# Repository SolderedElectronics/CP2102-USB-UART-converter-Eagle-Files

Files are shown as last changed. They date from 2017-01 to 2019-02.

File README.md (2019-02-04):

# CP2102 USB-UART adapter Eagle Files
## Image
CP2102 USB to UART adapter image
[CP2102 USB to UART adapter(100033)](https://e-radionica.com/en/usb-uart-adapter-with-cp2102-made-by-e-radionica.html)

## Description and details
This little adapter converts USB communication to UART using Silabs CP2102. Everything is packed on a small board. In addition to standard UART pins arranged in standard order: DTR, RXD, TXD, VCC, CTS, GND, other pins from the chip are available on the board: RST, Suspend, Suspend ', RI, DCD, DSR, RTS, CTS.

In addition, the board is a voltage regulator and a switch, it is possible to determine the output voltage of 3.3V or 5V, depending on the device you are using. Logic UART signal is always 3.3V, but do not worry, 5V devices will work without problems. There are also three LEDs, one for power indicator and one for each direction of UART communication.
 
- Dimensions: 25 x 35 mm
- USB - UART bridge: CP2102
- Input voltage: 5V (USB)
- Output voltage: 3.3V ili 5V
- Logic of UART signal: 3.3V

## Repository content
This repo contains Cadsoft Eagle .sch and .brd files for CO2102 breakout. It also contains schematic in .pdf created from .sch Eagle file. 
Files have been arranged into folders for navigating between different versions of board. 
Tip: layer 200 shows top silkscreen and layer 208 should be bottom silkscreen. tParts and bParts layers are not used in actual PCB. 

## Docs
- [CP2102 adapter product page](https://e-radionica.com/en/usb-uart-adapter-with-cp2102-made-by-e-radionica.html)

## Board versions
- v1.0 REV A - inital published version 

## License info
This product is open-source. Yay!
For any tech questions, contact us at techsupport@e-radionica.com
If you find an Issue, please open one at GitHub. If you can improve our product, fork us.

e-radionica.com Team.

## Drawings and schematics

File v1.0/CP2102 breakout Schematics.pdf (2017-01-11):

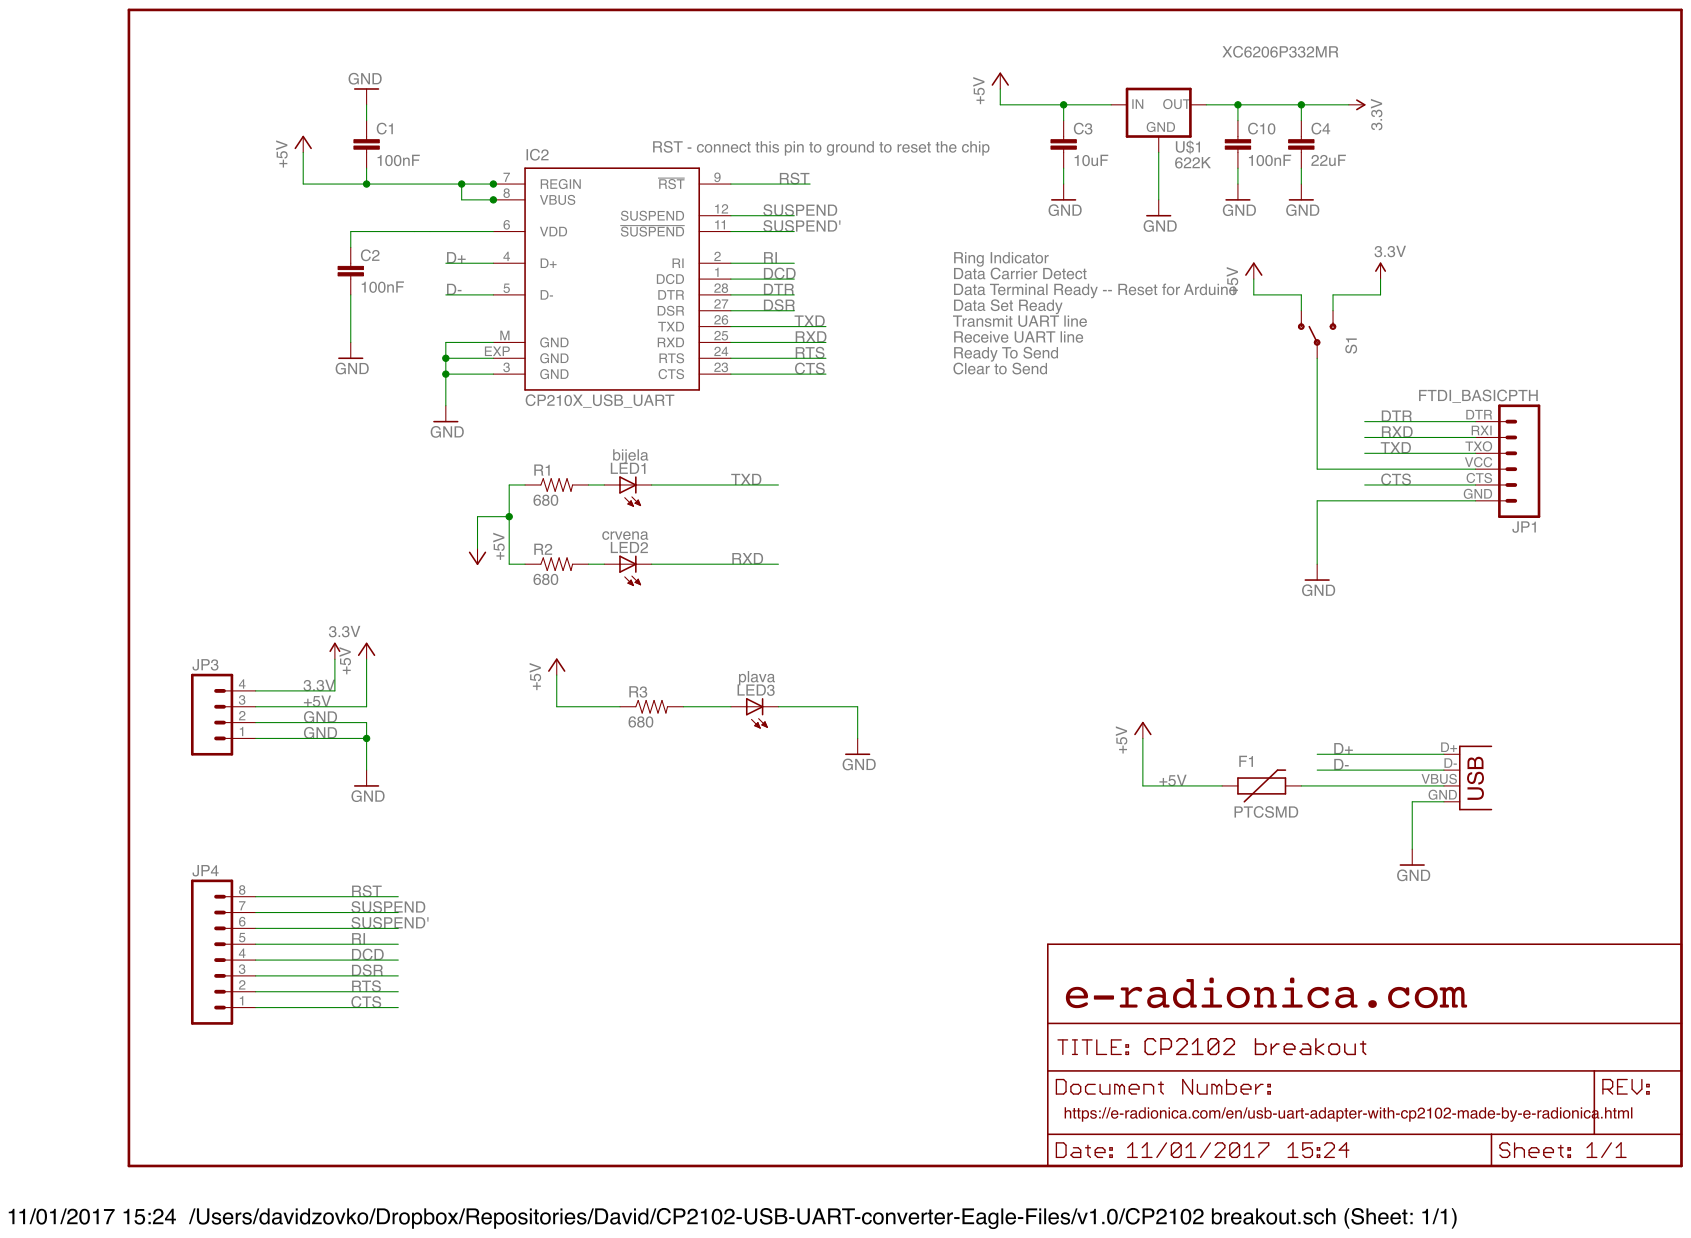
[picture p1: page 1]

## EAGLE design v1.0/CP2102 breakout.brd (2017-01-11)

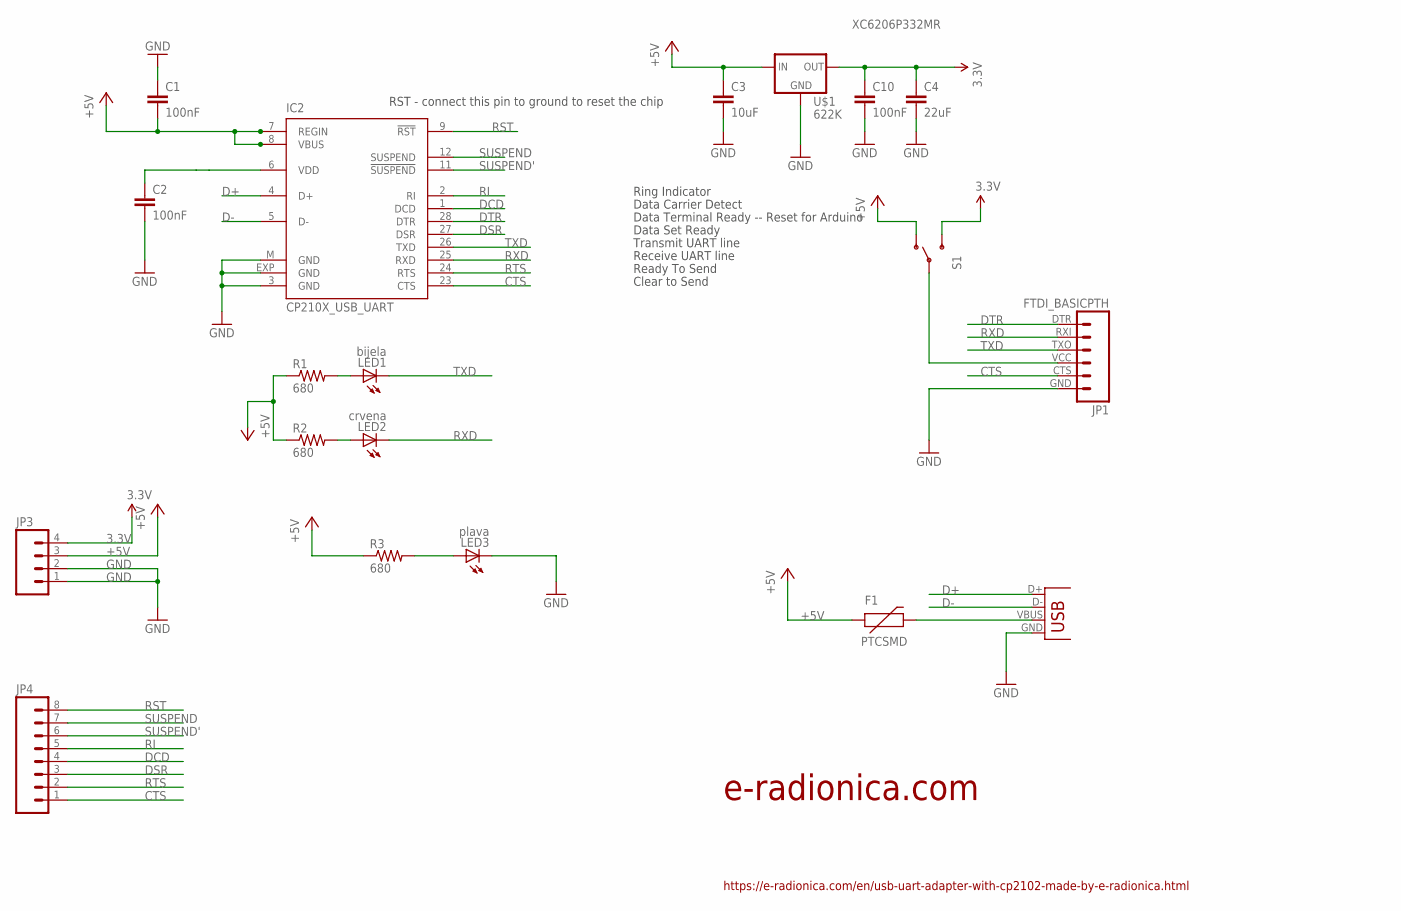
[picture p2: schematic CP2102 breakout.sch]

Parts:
C1, C2, C10: 100nF; 0603-CAP
C3: 10uF; C3216
C4: 22uF; C3216
F1: PTCSMD; PTC-1206
IC2: CP210X_USB_UART; MLP28
JP1: FTDI_BASICPTH; FTDI_BASIC
JP3: M04PTH; 1X04
JP4: M081X08; 1X08
LED1: bijela; CHIP-LED0805
LED2: crvena; CHIP-LED0805
LED3: plava; CHIP-LED0805
R1, R2, R3: 680; 0603-RES
S1: SWITCH-SPST-SMD-A
U$1: 622K; 662K
X1: USB-MICROB

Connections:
3.3V: C4.1, C10.1, JP3.4, S1.3 (S), U$1.OUT
+5V: C1.2, C3.1, F1.1, IC2.7 (REGIN), IC2.8 (VBUS), JP3.3, R1.1, R2.1, R3.1, S1.1 (O), U$1.IN
CTS: IC2.23 (CTS), JP1.CTS (5), JP4.1
D+: IC2.4 (D+), X1.D+
D-: IC2.5 (D-), X1.D-
DCD: IC2.1 (DCD), JP4.4
DSR: IC2.27 (DSR), JP4.3
DTR: IC2.28 (DTR), JP1.DTR (1)
GND: C1.1, C2.2, C3.2, C4.2, C10.2, IC2.3 (GND), IC2.EXP (GND), IC2.M (GND), JP1.GND (6), JP3.1, JP3.2, LED3.C, U$1.GND, X1.GND
unnamed: LED1.A, R1.2
unnamed: LED2.A, R2.2
unnamed: LED3.A, R3.2
unnamed: C2.1, IC2.6 (VDD)
RI: IC2.2 (RI), JP4.5
RST: IC2.9 (!RST), JP4.8
RTS: IC2.24 (RTS), JP4.2
RXD: IC2.25 (RXD), JP1.RXI (2), LED2.C
SUSPEND: IC2.12 (SUSPEND), JP4.7
SUSPEND': IC2.11 (!SUSPEND), JP4.6
TXD: IC2.26 (TXD), JP1.TXO (3), LED1.C
VBUS: F1.2, X1.VBUS
VCC: JP1.VCC (4), S1.2

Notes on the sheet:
RST - connect this pin to ground to reset the chip
Clear to Send
Data Terminal Ready -- Reset for Arduino
Data Set Ready
Transmit UART line
Receive UART line
Data Carrier Detect
Ring Indicator
Ready To Send
XC6206P332MR
https://e-radionica.com/en/usb-uart-adapter-with-cp2102-made-by-e-radionica.html
e-radionica.com

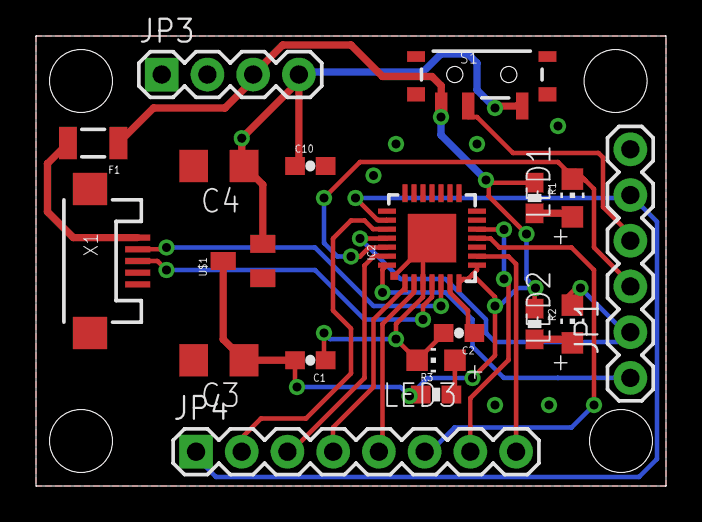
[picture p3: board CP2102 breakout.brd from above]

Board: 2 copper layers, 35.0 x 25.0 mm, 23 parts (0 on the bottom side), 22 nets.

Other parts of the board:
U$2: OSH3MM
U$3: NOVI_LOGO-4MM
U$4: LUDI_LOGO_BACK
U$5: E-RADIONICA.COM_MADE_IN_BACK!

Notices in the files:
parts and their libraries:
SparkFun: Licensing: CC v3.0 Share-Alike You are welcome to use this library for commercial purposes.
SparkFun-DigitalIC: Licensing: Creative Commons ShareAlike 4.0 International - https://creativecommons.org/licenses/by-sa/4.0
